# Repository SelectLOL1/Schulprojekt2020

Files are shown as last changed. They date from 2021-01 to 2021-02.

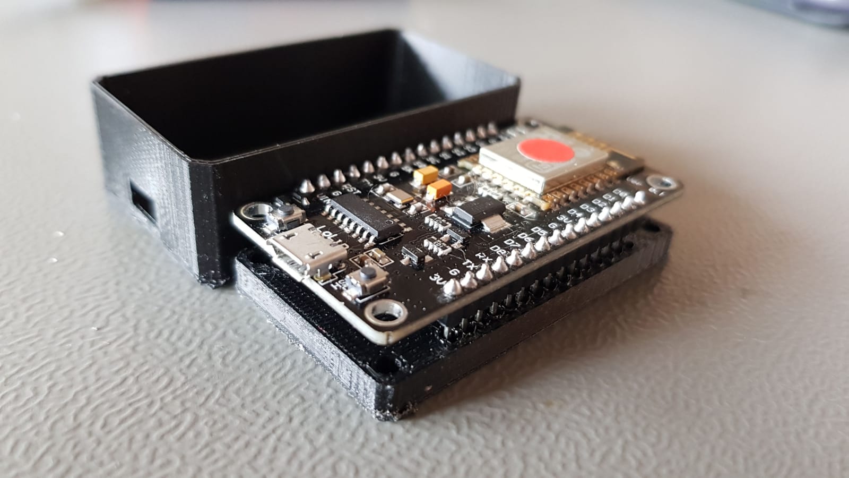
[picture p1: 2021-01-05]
images/mechanicalDemo.png

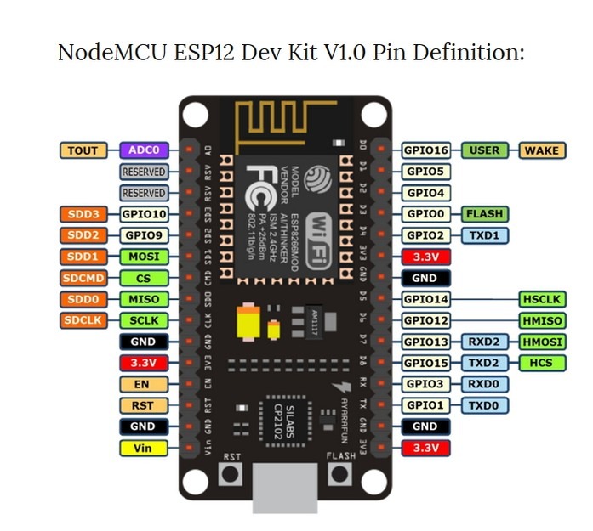
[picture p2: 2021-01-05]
images/pinout.png

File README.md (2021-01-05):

# Schulprojekt2020
Schulprojekt2020 bei Räschle

Pi-Software:
Node-Red
Mosquitto Broker

1. Funktionierende Version: 28.12.2020;
   Verbesserungen = Diverse...

Gute Websites:

https://randomnerdtutorials.com/getting-started-with-node-red-on-raspberry-pi/ 05.11.2020

https://randomnerdtutorials.com/esp8266-and-node-red-with-mqtt/ 05.11.2020

https://github.com/pimoroni/node-red-nodes 06.11.2020 (Achtung!! Pfad /home/pi/.node-red/nodes/ erstellen und dann git klonen.)

Notes:
Nicht Python3 als standard einstellen sonst kackt Pimmeroni Blinkt ab, python3 funktionen sind python2!

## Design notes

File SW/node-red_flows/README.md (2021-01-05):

# StableEnoughVersion 1.0:
## MainFlow:
MQTT node bekommt daten.
pieceofshitsoftware wandelt daten die in einem char array(dec. values) gefuellten daten und schreibt sie in ASCII um und fuellt die werte einzeln in eine liste.
DoWeKnowThisDevice generiert einen pfad der die position eines neu ankommenden ESPs in eine CSV Datei speichert. Die in ASCII umgewandelten werte werden parst usw... der code ist selbstverstaendlich. Es wird am schluss ein positionswert mitgeschickt am return
PosxListener wartet auf die jeweilige position ab und parst und schickt die werte an die jeweiligen text nodes.
## SetThresholds:
Der User definiert thresholds die schlussendlich indirekt die LEDs ansteuern. Die werte werden in files geschpeichrt und readlefilexxxMin/Max liest die werte aus den jeweiligen datein da nodered die werte beim neu aufstarten nicht speichert. VerifyTheThresholds schaut dass die Min werte nicht ueber den Max werten sind. Sonst wird ein error geschrieben.
## RGBControlling:
Die ausgehenden werte von DoWeKnowThisDevice werden mit den thresholds verglichen und dann jenachdem welcher ESP welchen wert unter/ueberschritten hat, wird eine LED mit verschiedenen farb angesteuert. Der rest sorgt dafuer, dass die LED nicht aufhoert zu blinken, solang die werte nicht in den thresholds sind. Grobe beschreibung aller nodes.

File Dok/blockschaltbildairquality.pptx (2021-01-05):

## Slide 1

5V Schaltnetzteil

Basisstation

18650 Zelle

ESP8266

Gas Sensor

SGP30

5V

3.7V

I²C

2.4GHz Wlan

Raspberry Pi Zero

6x RGB LEDs

SHT3x-DIS

Luft-feutcht./temp. Sensor

6x Module

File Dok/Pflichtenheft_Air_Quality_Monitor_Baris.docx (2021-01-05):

Pflichtenheft

Air Quality

Monitor


Abbildung 1: Ein ESP8266 im Testgehäuse

Gewerbliche Berufsschule Chur

Bereichsübergreifende Projekte

ELT7A

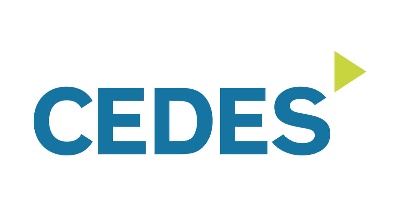
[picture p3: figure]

Erstellt von: Baris Catan (BCA)

Lehrer: Felix Räschle

Lehrmeister: Michael Flury

Betrieb: Cedes AG

Abgabe: 05.10.2020

Version: 1.1

# 1. Einführung

Diese Projektarbeit soll als Vorarbeit für die Individuelle Praktische Arbeit (IPA) dienen, welche jeder Elektroniker im 4. Lehrjahr absolvieren muss. Die IPA ist ein starkes Bewertungskriterium im Qualifikationsverfahren und macht 25% der Endnote aus.

# 2. Informationen zum Projekt

## 2.1 Aufgabenstellung

Jeder Lernender soll ein eigenes, machbares Projekt auf die Beine stellen. Er soll eine gute Dokumentation, d.h. Pflichtenheft, Zeitplan und Dokumentation erstellen.

## 2.2 Zeitvorgaben

Für diese Arbeit darf maximal 50 Stunden investiert werden. Damit man eine Kontrolle über den Zeitverlauf hat, wird ein Zeitplan erstellt. Dieser Zeitplan ist auch relevant für die Bewertung.

## 2.3 Wahl des Projekts

Die Qualität der Luft, die wir einatmen kann, einen grossen Effekt auf die kognitive Fähigkeit und der Konzentration haben. Um zu wissen welches Zimmer wann gelüftet werden soll, empfängt eine Basisstation die Informationen bezüglich der Luftqualität von bis zu sechs Modulen gleichzeitig. Die Informationen bezüglich der Luftqualität werden auf der Basisstation durch sechs RGB LEDs und durch eine Webseite, die von der Basisstation gehostet wird, ersichtlich. Auf der Webseite soll man auch vergangene Werte anschauen können.

## 2.4 Ausgangslage

Für mein Projekt verwende ich einen Raspberry Pi Zero und sechs einzeln ansteuerbare RGB LEDs als Basisstation. Die Basisstation wird durch ein normales Schaltnetzteil, dass mit dem Raspberry Pi mitgeliefert wird gespiesen.

Die einzelnen Module, die die Luftqualität überwachen, bestehen aus einem ESP8266, ein Wlan-Fähiges und Arduino kompatibles Modul mit GPIOS und diversen Schnittstellen. Zu diesen Modulen gehören noch jeweils zwei Sensirion Sensoren, nämlich der SGP30 Gas Sensor und SHT3x-DIS Luftfeuchtigkeit und Temperatur Sensor. Beide Sensoren benützen die I2C Schnittstelle, um mit dem ESP8266 zu kommunizieren und sollten einen guten Einblick in die Qualität der Luft geben. Die Module werden mit der Basisstation über Wlan (2.4GHz) kommunizieren.

# 3 Geplantes Projekt

## 3.1 Anforderungen an das Projekt

Alle Zeiten sollen wie vorgegeben eingehalten werden. Die Dokumentation soll informativ, übersichtlich und vollständig sein.

## 3.2 Ziele des Projekts

Alle sechs Module sollen jeweils von einer 18650 Lithium Ionen Zelle für mindestens drei Monate funktionieren.

Die Module soll man über einen USB-Typ C Anschluss laden können.

Auf der Webseite der Basisstation sollen die daten graphisch dargestellt werden, dazu sollen noch vergangene Werte bis zu mindestens einen Monat in die Vergangenheit angeschaut werden können.

Während meines Projekts sollen folgende Teilziele erreicht werden:

- Erstellung Dokumentation
  - Pflichtenheft
  - Zeitplan
  - Ausführliche Dokumentation
- Erstellung Hardware
  - Steckbare Leiterplatte für Sensoren und Ladeschaltkreis
  - Gehäuse
- Erstellung Software
  - Struktogramm
  - Code für Module
  - Code für Basisstation
- Inbetriebnahme
  - Inbetriebnahme-Protokoll
  - Allfällige Verbesserungen

# 4 Geplantes Projekt

## 4.1 Blockschaltbild

Abbildung 2: Blockschaltbild

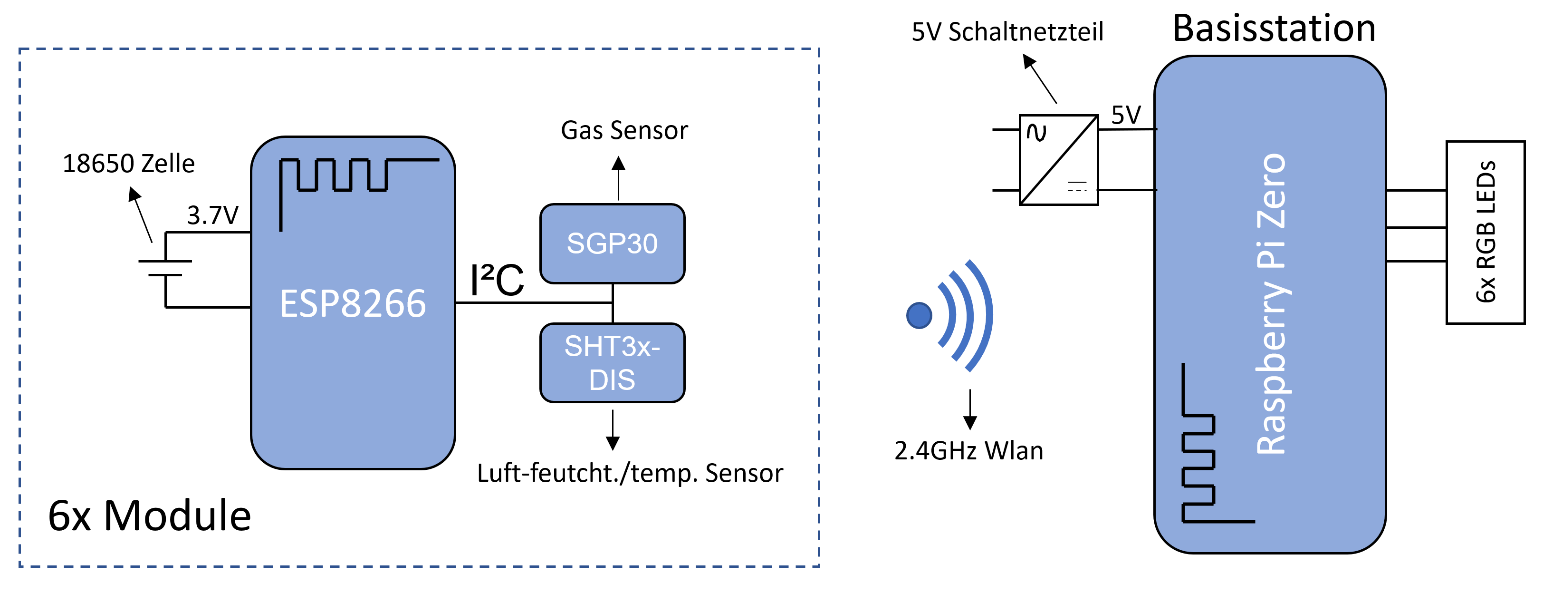
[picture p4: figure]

## 4.2 Hardware

- ESP8266 (Mikrocontroller)
  - Ein Wlan fähiger und mit der Arduino IDE kompatibler Mikrocontroller. Er ist dafür zuständig, die Daten der Sensoren über I²C auszulesen, auszuwerten und der Basisstation weiterzuleiten.
- SGP30 (Gas Sensor)
  - Gas Sensor von Sensirion. Mist Ethanol, Wasserstoff, TVOC (Total Volatile Organic Compounds) und CO2. Die Werte können über I²C ausgelesen werden.
- SHT3X-DIS (Luft-temperatur / feuchtigkeitssensor)
  - Luft-temperatur / feuchtigkeitssensor von Sensirion. Die Werte können über I²C ausgelesen werden.
- 18650 Zelle (Akkumulator)
  - Falls das Modul nicht an einer festen Stromversorgung angeschlossen ist, wird es über die 18650 Zelle gespiesen.
- Raspberry Pi Zero (System On Module)
  - Die Basisstation besteht aus dem Raspberry Pi Zero. Dessen Aufgabe ist es, die Werte der Module zu empfangen und auf den RGB LEDs und der Website anzuzeigen.
- 5V Schaltnetzteil (Speisung Raspberry Pi Zero)
  - Das mit dem Raspberry Pi Zero mitgelieferte Schaltnetzteil wird als Speisung verwendet.
- WS2812B (RGB LED`s)
  - Sechs RGB LED`s für sechs Module. Jede LED zeigt grün für gute Luftqualität an und rot für schlechte. Alles dazwischen geschieht mit einem Farbdurchlauf von rot nach grün oder umgekehrt.

## 4.3 Software

Die Software wird voraussichtlich für den ESP8266 mit der zurzeit neusten Version der Arduino IDE in den Programmiersprachen: C/C++ programmiert.

Für den Raspberry Pi Zero werde ich zum grössten Teil Python und NodeRED benützen.

# 5 Geplantes Projekt

## 5.1 Kosten

CHF 150.- von den Kosten für dieses Projekt werden von der Firma CEDES AG übernommen, den Rest zahle ich selbst.

## 5.2 Zeitplan

Der Zeitplan wurde mit in Form einer Excel Tabelle erstellt.

## 5.3 Dokumentation

Begleitet zum Projekt wird laufend an der Dokumentation gearbeitet.

# 6. Anhang

## 6.1 Abbildungsverzeichnis

05.10.2020 Pflichtenheft Air Quality Monitor 1 / 5

Catan Baris ELT7A

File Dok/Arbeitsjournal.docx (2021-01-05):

Arbeitsjournal

Gewerbliche Berufsschule Chur

Bereichsübergreifende Projekte

ELT5A

Erstellt von: Catan Baris (BCA)

Datum: 30.10.2019

Version: 1.1

Verantwortlich: Flury, Michael Lehrmeister, CEDES AG

Rupp, Patric Lehrperson, GBC

Datum | Dauer | Arbeitsort | Tätigkeit | Resultat | Erkenntnisse / Probleme
14.08.2019 | 2h | Cedes | Zeitplan/Pflichtenheft erstellen | Zeitplan/Pfilichtenheft erstellt | Es gab keine Komplikationen
16.08.2019 | 1h | Cedes | Grobdispo und Kosten überdenken | Grobdisko und Kosten überdenkt | Es gab keine Komplikationen
16.08.2019 | 1h | Cedes | Planung der Hardware und Planung der Bestellung der Bauteile | Hardware und Bestellung wurden geplant | Es gab keine Komplikationen
19.08.2019 | 3h | Cedes | Schema des Huckepackprints erstellen | Schema des Huckpackprints wurde erstellet | Werte einiger Bauteile geschätzt, Berechnung erst vor dem bestücken, um Zeit zu sparen und so schnell wie möglich Bestellung für PCB rausgeben.
20.08.2019 | 2h | Cedes | Nach einem DC-DC Boost Converter recherchieren und aufbauen | Geeignetes Schema gefunden und Converter wurde aufgebaut | DC-DC Boost Converter funktioniert einwandfrei.
21.08.2019 | 3h | Cedes | Schema des Hauptprints erstellen | Schema des Hauptprints wurde erstellet | Werte einiger Bauteile geschätzt, Berechnung erst vor dem bestücken, um Zeit zu sparen und so schnell wie möglich Bestellung für PCB rausgeben.
22.08.2019 | 1h | GBC | Schemen mit Mitschüler anschauen | Schemen wurden mit Mitschüler angeschaut | Es gab keine Komplikationen
23.08.2019 | 1h | Cedes | Mit dem Layout vom Huckepackprint anfangen | Mit dem Layout vom Huckepackprint wurde angefangen | Da es mein erstes Layout ist, musste ich mich ans Altium zuerst mal gewöhnen
24.08.2019 | 2h | Zuhause | Am Layout vom Huckepackprint weitermachen | Am Layout vom Huckepackprint wurde weitergemacht | Es gab keine Komplikationen
30.08.2019 | 1h | Cedes | Layout Review mit Lehrmeister | Layout wurde mit Lehrmeister gereviewt | Einige Fehler wurden gefunden und zeitgleich behoben
04.09.2019 | 2h | Cedes | Mit dem Layout vom Hauptprint anfangen | Mit dem Layout vom Hauptprint wurde angefangen | Es gab keine Komplikationen
06.09.2019 | 1h | Cedes | Layout Review mit Lehrmeister | Layout wurde mit Lehrmeister gereviewt | Einige Fehler wurden gefunden und zeitgleich behoben

30.10.2019ArbeitsjournalSeite 2 / 2 Projektarbeit Nixie-Uhr

Baris Catan ELT5A

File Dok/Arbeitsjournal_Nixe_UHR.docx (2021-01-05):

Arbeitsjournal

Gewerbliche Berufsschule Chur

Bereichsübergreifende Projekte

ELT5A

Erstellt von: Catan Baris (BCA)

Datum: 15.12.2019

Version: 1.1

Verantwortlich: Flury, Michael Lehrmeister, CEDES AG

Rupp, Patric Lehrperson, GBC

Datum | Dauer | Arbeitsort | Tätigkeit | Resultat | Erkenntnisse / Probleme
14.08.2019 | 1h | Cedes | Zeitplan/Pflichtenheft erstellen | Zeitplan/Pfilichtenheft erstellt | Es gab keine Komplikationen
16.08.2019 | 1h | Cedes | Grobdispo und Kosten überdenken | Grobdisko und Kosten überdenkt | Es gab keine Komplikationen
16.08.2019 | 1h | Cedes | Planung der Hardware und Planung der Bestellung der Bauteile | Hardware und Bestellung wurden geplant | Es gab keine Komplikationen
19.08.2019 | 3h | Cedes | Schema des Huckepackprints erstellen | Schema des Huckpackprints wurde erstellet | Werte einiger Bauteile geschätzt, Berechnung erst vor dem bestücken, um Zeit zu sparen und so schnell wie möglich Bestellung für PCB rausgeben.
20.08.2019 | 1h | Cedes | Nach einem DC-DC Boost Converter recherchieren und aufbauen | Geeignetes Schema gefunden und Converter wurde aufgebaut | DC-DC Boost Converter funktioniert einwandfrei.
21.08.2019 | 2h | Cedes | Schema des Hauptprints erstellen | Schema des Hauptprints wurde erstellet | Werte einiger Bauteile geschätzt, Berechnung erst vor dem bestücken, um Zeit zu sparen und so schnell wie möglich Bestellung für PCB rausgeben.
22.08.2019 | 1h | GBC | Schemen mit Mitschüler anschauen | Schemen wurden mit Mitschüler angeschaut | Es gab keine Komplikationen
23.08.2019 | 1h | Cedes | Mit dem Layout vom Huckepackprint anfangen | Mit dem Layout vom Huckepackprint wurde angefangen | Da es mein erstes Layout ist, musste ich mich ans Altium zuerst mal gewöhnen
24.08.2019 | 2h | Zuhause | Am Layout vom Huckepackprint weitermachen | Am Layout vom Huckepackprint wurde weitergemacht | Es gab keine Komplikationen
30.08.2019 | 1h | Cedes | Layout Review mit Lehrmeister | Layout wurde mit Lehrmeister gereviewt | Einige Fehler wurden gefunden und zeitgleich behoben
04.09.2019 | 2h | Cedes | Mit dem Layout vom Hauptprint anfangen | Mit dem Layout vom Hauptprint wurde angefangen | Es gab keine Komplikationen
06.09.2019 | 1h | Cedes | Layout Review mit Lehrmeister | Layout wurde mit Lehrmeister gereviewt | Einige Fehler wurden gefunden und zeitgleich behoben
21.10.2019 | 3h | Cedes | Prints bestücken | Beide Leiterplatten wurden erfolgreich bestückt | Es gab keine Komplikationen
23.10.2019 | 2h | Cedes | DC-DC Converter aufbauen | Converter erfolgreich aufgebaut | Es gab keine Komplikationen
25.10.2019 | 4h | Cedes | An der Dokumentation ‘Hardware’ schreiben (Milestone 1) | Dieser Teil wurde erfolgreich geschrieben | Es gab keine Komplikationen
28.10.2019 | 3h | Cedes | Struktogramm machen | Struktogramm wurde erfolgreich gemacht | Es gab keine Komplikationen
04.11.2019 | 3h | Cedes | Sicher über I2C informieren und I2C implementieren | I2C wurde teilweise implementiert | Es gab kleine Komplikationen die nachher behoben werden.
08.11.2019 | 3h | Cedes | Software zur Verarbeitung der Messwerte schreiben | Software zur Verarbeitung der Messwerte wurde geschrieben | Es gab keine Komplikationen
11.11.2019 | 3h | Cedes | Software zur Ausgabe schreiben | Software zur Ausgabe wurde schreiben und I2C Komplikationen wurden behoben | Es gab keine Komplikationen
18.11.2019 | 3h | Cedes | Dokumentation ‘Software’ schreiben (Milestone 2) | Dokumentation ‘Software’ wurde geschrieben | Es gab keine Komplikationen
22.11.2019 | 3h | Cedes | Inbetriebnahme (Milestone 3) | Einige Fehler wurden gefunden und problemlos behoben | Es gab keine Komplikationen
27.11.2019 | 2h | Cedes | Dokumentation ‘Inbetriebnahme’ schreiben | Dokumentation ‘Inbetriebnahme’ wurde geschrieben | Es gab keine Komplikationen
04.12.2019 | 1h | Zuhause | An der Dokumentation schreiben | Dokumentation braucht noch einen feinschliff | Es gab keine Komplikationen
15.12.2019 | 3h | Zuhause | An der Dokumentation schreiben (Milestone 4) | Dokumentation fertig | Es gab keine Komplikationen

15.12.2019Arbeitsjournal 2 / 2 Projektarbeit Nixie-Uhr

Baris Catan ELT5A

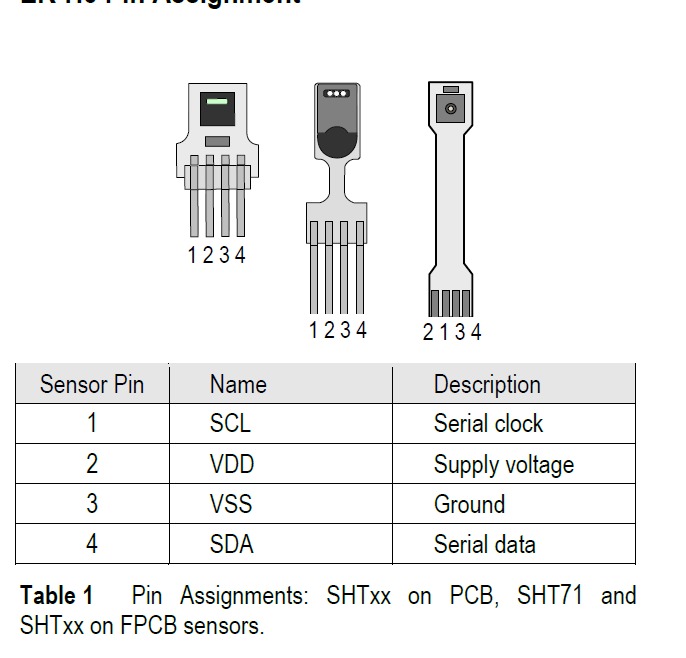
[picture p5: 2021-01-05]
images/shtxxPinout.png

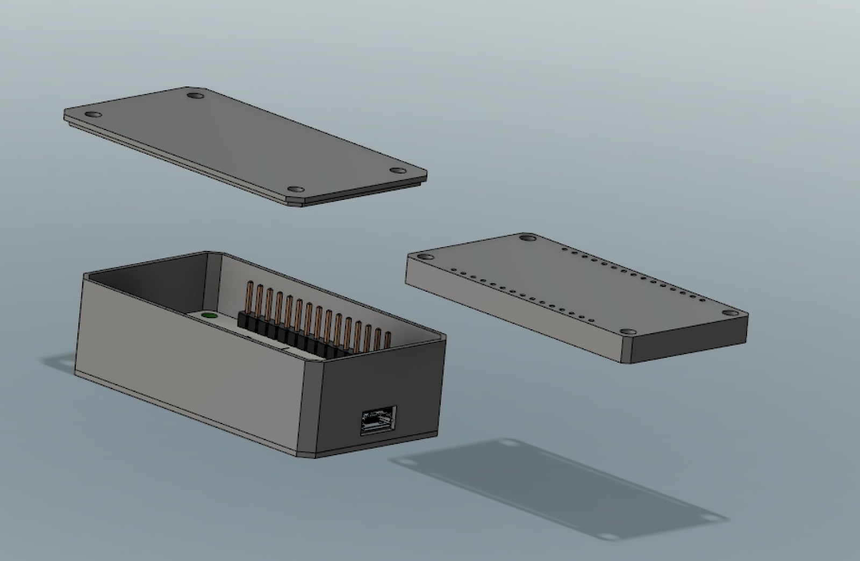
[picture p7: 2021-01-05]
images/housing.png

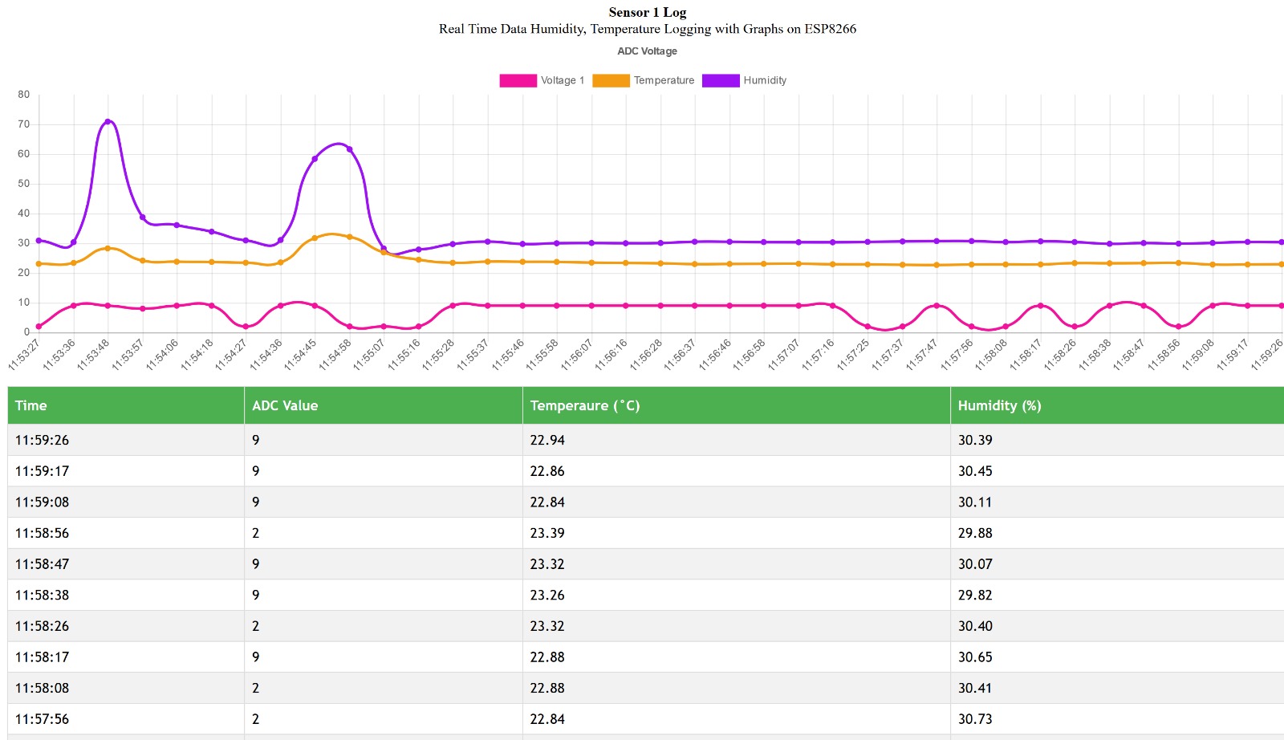
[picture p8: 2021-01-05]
images/webpage.png

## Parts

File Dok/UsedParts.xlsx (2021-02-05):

Battery charger IC 1x | BQ24093DGQT | CHF 1.19 | https://www.digikey.ch/product-detail/de/texas-instruments/BQ24093DGQT/296-BQ24093DGQTCT-ND/2325835
LiIon | Samsung 35E | CHF 5.80 | https://www.reichelt.com/ch/de/industriezelle-18650-3-6-v-3450-mah-ungeschuetzt-1er-pack-sam-18650-35e-s-p278070.html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
LiPo | Alles teuer | Lieber nicht
BuckBoostConverter | MCP1640T-I/CHY | CHF 0.52 | https://www.digikey.ch/product-detail/de/microchip-technology/MCP1640T-I%2FCHY/MCP1640T-I%2FCHYCT-ND/2258621?productid=2258621
BatterieHalter | 54 | CHF 0.58 | https://www.digikey.ch/product-detail/de/keystone-electronics/54/36-54-ND/2254090
Batterieverlaengerung Female 6stck | PPPC032LFBN-RC | CHF 0.57 | https://www.digikey.ch/product-detail/de/sullins-connector-solutions/PPPC032LFBN-RC/S7106-ND/810243
Batterieverlaengerung Male 6stck | 929715-06-03-EU | CHF 0.92 | https://www.digikey.ch/product-detail/de/3m/929715-06-03-EU/3M156375-06-ND/3834375
Spule Buck converter | SDET25201B-4R7MS | CHF 0.19 | https://www.digikey.ch/product-detail/de/delta-electronics-cyntec/SDET25201B-4R7MS/2037-SDET25201B-4R7MSCT-ND/10315560
Widerstand | 620k | CHF 0.09 | https://www.digikey.ch/product-detail/de/panasonic-electronic-components/ERA-6AED624V/P123868CT-ND/9467797

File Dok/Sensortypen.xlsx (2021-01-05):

Name | Wlan | Luftqualität IAQ | Temperatur | Gas | Feuchte | Druck | Schnittstelle | Spannungsversorgung | Preis | Kommentar
esp8266 | X
CCS811 |  | X |  |  |  |  | I2C | 3V-5V
BME680 |  |  | X | X | X | X | I2C, SPI | 3V-5V
BME280 |  |  | X |  | X | X

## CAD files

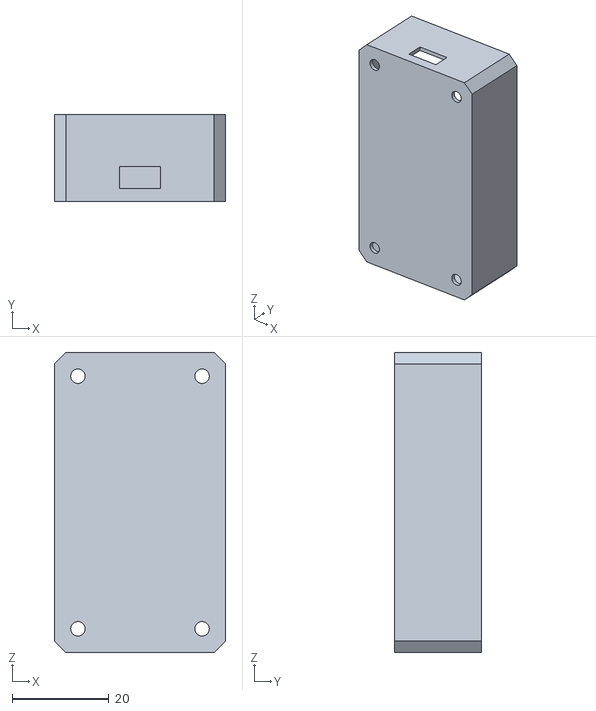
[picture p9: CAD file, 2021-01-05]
Mech/Boden_V001.stl
35.5 x 18.0 x 62.1

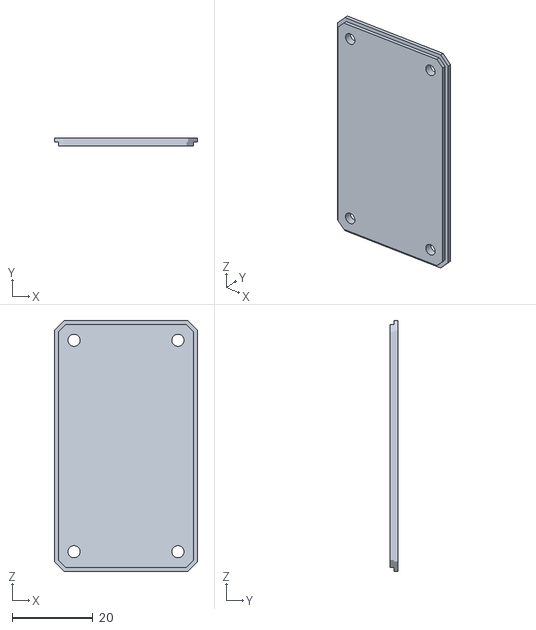
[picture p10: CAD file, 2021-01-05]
Mech/Deckel_V001.stl
35.5 x 2.00 x 62.1

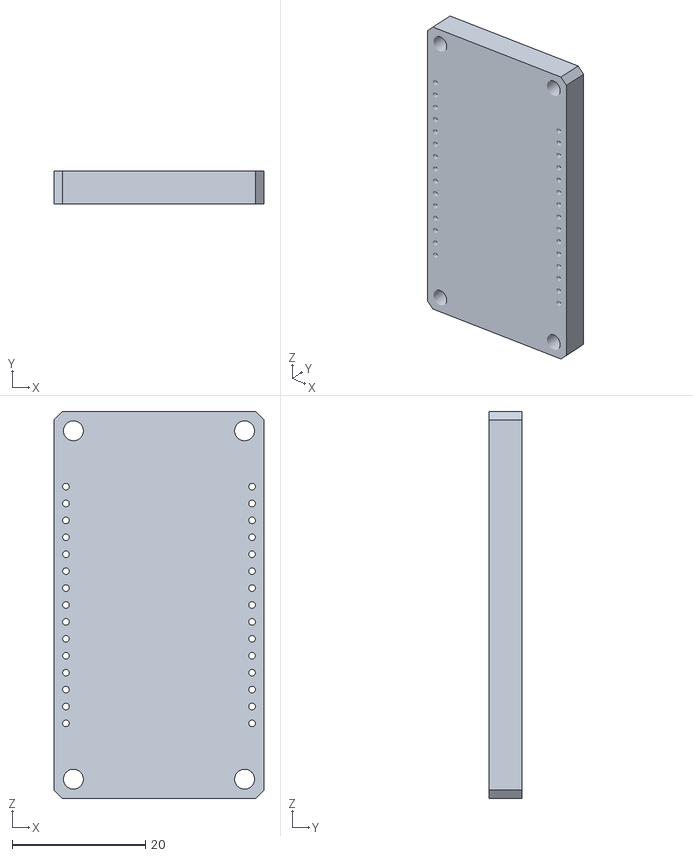
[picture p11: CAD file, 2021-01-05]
Mech/Dummy_V001.stl
31.5 x 5.00 x 58.1

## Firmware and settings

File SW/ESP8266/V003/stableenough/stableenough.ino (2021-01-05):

#include <ESP8266WiFi.h>
#include <PubSubClient.h>
#include <Wire.h>

unsigned char buf[20];
unsigned char opt_sensors;
int incomingByte = 0;
int loopCount = 0;
char showTemp = 1, showHum = 1, showLight = 1, showSound = 1, showCO2 = 1, showVOC = 1, showPwr = 1, showEvents = 0;

float sampPeriod = 500;

const char* ssid = "iOsw8tVh3w2";
const char* password = "password :)";

// Change the variable to your Raspberry Pi IP address, so it connects to your MQTT broker
const char* mqtt_server = "192.168.25.203";

// Initializes the espClient. You should change the espClient name if you have multiple ESPs running in your home automation system
WiFiClient espClient;
PubSubClient client(espClient);

// Timers auxiliar variables
long now = millis();
long lastMeasure = 0;

// Don't change the function below. This functions connects your ESP8266 to your router
void setup_wifi() {
  delay(10);
  // We start by connecting to a WiFi network
  Serial.println();
  Serial.print("Connecting to ");
  Serial.println(ssid);
  WiFi.begin(ssid, password);
  while (WiFi.status() != WL_CONNECTED) {
    delay(500);
    Serial.print(".");
  }
  Serial.println("");
  Serial.print("WiFi connected - ESP IP address: ");
  Serial.println(WiFi.localIP());
}

// This functions is executed when some device publishes a message to a topic that your ESP8266 is subscribed to
// Change the function below to add logic to your program, so when a device publishes a message to a topic that
// your ESP8266 is subscribed you can actually do something
void callback(String topic, byte* message, unsigned int length) {
  Serial.print("Message arrived on topic: ");
  Serial.print(topic);
  Serial.print(". Message: ");
  String messageTemp;

  for (int i = 0; i < length; i++) {
    Serial.print((char)message[i]);
    messageTemp += (char)message[i];
  }
  Serial.println();

  // Feel free to add more if statements to control more GPIOs with MQTT

  Serial.println();
}

// This functions reconnects your ESP8266 to your MQTT broker
// Change the function below if you want to subscribe to more topics with your ESP8266
void reconnect() {
  // Loop until we're reconnected
  while (!client.connected()) {
    Serial.print("Attempting MQTT connection...");
    // Attempt to connect
    /*
      YOU MIGHT NEED TO CHANGE THIS LINE, IF YOU'RE HAVING PROBLEMS WITH MQTT MULTIPLE CONNECTIONS
      To change the ESP device ID, you will have to give a new name to the ESP8266.
      Here's how it looks:
       if (client.connect("ESP8266Client")) {
      You can do it like this:
       if (client.connect("ESP1_Office")) {
      Then, for the other ESP:
       if (client.connect("ESP2_Garage")) {
      That should solve your MQTT multiple connections problem
    */
    if (client.connect("ESP8266Client")) {
      Serial.println("connected");
      // Subscribe or resubscribe to a topic
      // You can subscribe to more topics (to control more LEDs in this example)
    } else {
      Serial.print("failed, rc=");
      Serial.print(client.state());
      Serial.println(" try again in 5 seconds");
      // Wait 5 seconds before retrying
      delay(1000);
    }
  }
}

// The setup function sets your ESP GPIOs to Outputs, starts the serial communication at a baud rate of 115200
// Sets your mqtt broker and sets the callback function
// The callback function is what receives messages and actually controls the LEDs
void setup() {
  Serial.begin(115200);
  setup_wifi();
  client.setServer(mqtt_server, 1883);
  client.setCallback(callback);
  Wire.begin();
}

// For this project, you don't need to change anything in the loop function. Basically it ensures that you ESP is connected to your broker
void loop() {
  if (!client.connected()) {
    delay(random(150, 500));
    reconnect();
  }
  if (!client.loop())
    client.connect("ESP8266Client");

  now = millis();
  // Publishes new temperature and humidity every 30 seconds
  if (now - lastMeasure > 1000) {
    // All sensors except the CO2 sensor are scanned in response to this command
    Wire.beginTransmission(0x2A); // transmit to device
    // Device address is specified in datasheet
    Wire.write(byte(0xC0));       // sends instruction to read sensors in next byte
    Wire.write(0xFF);             // 0xFF indicates to read all connected sensors
    Wire.endTransmission();       // stop transmitting
    // Delay to make sure all sensors are scanned by the AmbiMate
    delay(100);

    Wire.beginTransmission(0x2A); // transmit to device
    Wire.write(byte(0x00));       // sends instruction to read sensors in next byte
    Wire.endTransmission();       // stop transmitting
    Wire.requestFrom(0x2A, 15);    // request 6 bytes from slave device

    // Acquire the Raw Data
    unsigned int i = 0;
    while (Wire.available()) { // slave may send less than requested
      buf[i] = Wire.read(); // receive a byte as character and store in buffer
      i++;
    }

    unsigned int status = buf[0];
    float temperatureC = (buf[1] * 256.0 + buf[2]) / 10.0;
    float humidity = (buf[3] * 256.0 + buf[4]) / 10.0;
    unsigned int light = (buf[5] * 256.0 + buf[6]);
    float batVolts = ((buf[9] * 256.0 + buf[10]) / 1024.0) * (3.3 / 0.330);
    unsigned int co2_ppm = (buf[11] * 256.0 + buf[12]);
    unsigned int voc_ppb = (buf[13] * 256.0 + buf[14]);
    byte macaddr[6];
   
    WiFi.macAddress(macaddr);

    lastMeasure = now;

    // Check if any reads failed and exit early (to try again).
    if (isnan(humidity) || isnan(temperatureC) || isnan(co2_ppm) || isnan(voc_ppb)){
      Serial.println("Failed to read from sensor!");
      return;
    }

    char temperatureTemp[7];
    dtostrf(temperatureC, 6, 2, temperatureTemp);

    char humidityHum[7];
    dtostrf(humidity, 6, 2, humidityHum);
   
    char co2_ppmCO2[7];
    dtostrf(co2_ppm, 6, 2, co2_ppmCO2);

    char voc_ppbVOC[7];
    dtostrf(voc_ppb, 6, 2, voc_ppbVOC);

    char readytofuckingsend[85];
    const char *charmcaddr = reinterpret_cast<const char*>(macaddr);
    char myshitdelimiter[2] = {179,179};
    
    strcpy(readytofuckingsend,charmcaddr);
    strcat(readytofuckingsend,myshitdelimiter);
    strcat(readytofuckingsend,temperatureTemp);
    strcat(readytofuckingsend,myshitdelimiter);
    strcat(readytofuckingsend,humidityHum);
    strcat(readytofuckingsend,myshitdelimiter);
    strcat(readytofuckingsend,co2_ppmCO2);
    strcat(readytofuckingsend,myshitdelimiter);
    strcat(readytofuckingsend,voc_ppbVOC);
    strcat(readytofuckingsend,myshitdelimiter);
    
    Serial.println(readytofuckingsend);
    // Publishes Temperature and Humidity values
    client.publish("room/HoleInTheWall", readytofuckingsend);

    Serial.print("Humidity: ");
    Serial.print(humidity);
    Serial.print(" %\t Temperature: ");
    Serial.print(temperatureC);
    Serial.println("*C ");
    Serial.print(WiFi.macAddress());
    Serial.print("   ");
    Serial.print("co2 in ppm: ");
    Serial.println(co2_ppm);
    Serial.print("VOC in ppb: ");
    Serial.println(voc_ppb);
  }
}

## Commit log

2021-01-28 Layout Finished
    [Sensorboard.PcbDoc, Sensorboard.PrjPcb, Sensorboard.SchDoc]
2021-01-29 ready PCB for purchase
    [Sensorboard.GBL, Sensorboard.GBO, Sensorboard.GBS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]
2021-02-05 Bestellung bereit machen
    [UsedParts.xlsx]
